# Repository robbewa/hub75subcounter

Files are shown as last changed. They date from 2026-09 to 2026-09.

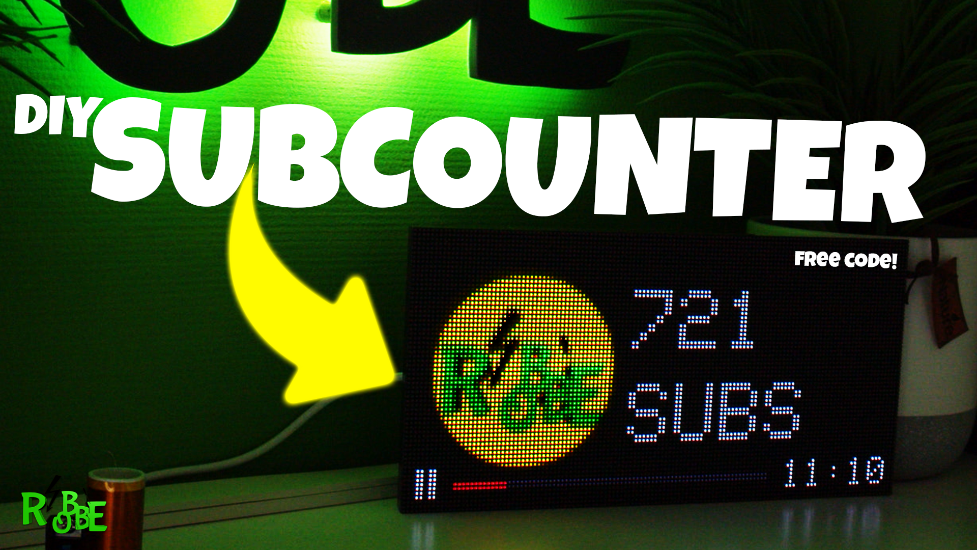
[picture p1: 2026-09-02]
thumb v2.png

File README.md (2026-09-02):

# ESP32 YouTube Subscriber Counter & HUB75 Matrix Display

An open-source, Wi-Fi-connected YouTube subscriber counter and multi-functional clock powered by an ESP32 and a 128x64 HUB75 LED matrix panel. 

It fetches real-time channel statistics via the YouTube Data API, displays a custom channel logo, includes an active YouTube-themed NTP clock, and triggers animated fireworks upon hitting subscriber milestones!

Watch the video (https://www.youtube.com/watch?v=sCw4Do6QDgE)

---

## Features

- **Live YouTube Stats:** Fetches and displays real-time subscriber counts using the YouTube Data API v3.
- **Custom Logo Integration:** Display your own 128x64 channel logo or graphic.
- **NTP Time Sync & YouTube Progress Bar:** Digital clock synced via NTP with a custom progress bar simulating a YouTube video player.
- **Milestone Animations:** Custom animated fireworks show whenever a new subscriber joins or a milestone is reached.
- **Automated Activity Scheduler:** Screen automatically turns on at 09:00 and off at 22:00 to save power and extend LED lifespan.
- **Display Rotation Support:** Software-configurable screen orientation (0°, 90°, 180°, 270°).
- **Custom 3D Printed Stand:** Dedicated magnetic enclosure with integrated USB-C power delivery.

---

## Hardware Requirements

- **Microcontroller:** ESP32 (e.g., ESP32-WROOM-32 / ESP32-S3)
- **Display Panel:** HUB75 LED Matrix Panel (128x64 pixels)
- **Power Supply:** 5V Power Supply / USB-C (ensure sufficient current capacity for the LED matrix)
- **Connector:** HUB75 ribbon cable (soldered directly to ESP32 for signal stability)
- **Enclosure:** Custom 3D-printed magnetic stand (STL files provided below)

---

## Pinout & Wiring Guide

>  **Important:** Standard jumper wires can cause severe signal interference on HUB75 panels. For optimal stability, it is strongly recommended to cut a HUB75 ribbon cable and solder the wires directly to the ESP32 GPIO pins.

| HUB75 Cable Wire | Function | ESP32 GPIO Pin |
| :--- | :--- | :--- |
| Wire 1 | R1 (Red 1) | GPIO 25 |
| Wire 2 | G1 (Green 1) | GPIO 26 |
| Wire 3 | B1 (Blue 1) | GPIO 27 |
| Wire 4 | GND | GND |
| Wire 5 | R2 (Red 2) | GPIO 14 |
| Wire 6 | G2 (Green 2) | GPIO 12 |
| Wire 7 | B2 (Blue 2) | GPIO 13 |
| Wire 8 | GND | GND |
| Wire 9 | A (Row Address) | GPIO 33 |
| Wire 10 | B (Row Address) | GPIO 32 |
| Wire 11 | C (Row Address) | GPIO 22 |
| Wire 12 | D (Row Address) | GPIO 19 |
| Wire 13 | CLK (Clock) | GPIO 4 |
| Wire 14 | LAT / LATCH | GPIO 2 |
| Wire 15 | OE (Output Enable) | GPIO 15 |
| Wire 16 | GND | GND |

*Note: Ensure the ESP32 ground (GND) and the HUB75 5V external power supply ground are connected to a common ground.*

---

## Quick Start & Setup

### 1. Prerequisites
- Install [Arduino IDE](https://www.arduino.cc/en/software).
- Add ESP32 Board Support to your Arduino IDE.
- Required Libraries: Install `ESP32-HUB75-MatrixPanel-I2S-DMA`, `ArduinoJson`, and `NTPClient` via the Library Manager.
- Obtain a YouTube Data API Key via the [Google Cloud Console](https://console.cloud.google.com/).

### 2. Preparing Image Assets
1. Create or resize your image to **128x64 pixels** in an image editor.
2. Convert the image using [image2cpp](https://endroad.net/env/image2cpp/).
3. Export the file as a `.h` header array and place it in your project directory.

### 3. Configuration & Flash
1. Clone or download this repository:
   ```bash
   git clone https://github.com/your-username/esp32-youtube-counter.git
   ```

2. Open the project in Arduino IDE and select your ESP32 board.
3. Update your credentials in the main sketch / configuration file:
```cpp
const char* ssid       = "YOUR_WIFI_SSID";
const char* password   = "YOUR_WIFI_PASSWORD";
const char* apiKey     = "YOUR_YOUTUBE_API_KEY";
const char* channelId  = "YOUR_YOUTUBE_CHANNEL_ID";
```

4. Set your preferred display orientation (`0`, `1`, `2`, or `3`).
5. Hold the **BOOT** button on your ESP32 (if required) and upload the code.

---

## 3D Printed Stand (Enclosure)

The repository includes printable STL files for a custom rear-mounting stand featuring:

* Recessed slots for M3 heat-set inserts / bolts.
* Magnet mounts for quick snap-on backplate removal.
* Integrated cutout for a panel-mount USB-C extension port.

 Find all model files in the `/3D_Files` directory.

---

## Video & Build Guide

Want to see how this project was built step-by-step or see it in action? Check out the full video tutorial on YouTube:

---

## License & Terms of Use

This project is open-source and shared strictly for personal and educational use.

This work is licensed under a **[Creative Commons Attribution-NonCommercial-ShareAlike 4.0 International License (CC BY-NC-SA 4.0)](https://creativecommons.org/licenses/by-nc-sa/4.0/)**.

```
    -  Attribution Required: You must give appropriate credit to Robbe Wauters and link back to this repository or the original YouTube channel.
    -  No Commercial Use: You may NOT sell, commercialize, package, or monetize this code, project files, or physical derivatives in any form.
    -  ShareAlike: If you remix, transform, or build upon the material, you must distribute your contributions under the same license as the original.

```

---

##  Credits & Author

Designed and developed by **Robbe Wauters**.

If you build your own version of this subscriber counter, feel free to share your build or tag me on social media! If this project helped you, consider subscribing to the channel or dropping a star on this repository.

```

```

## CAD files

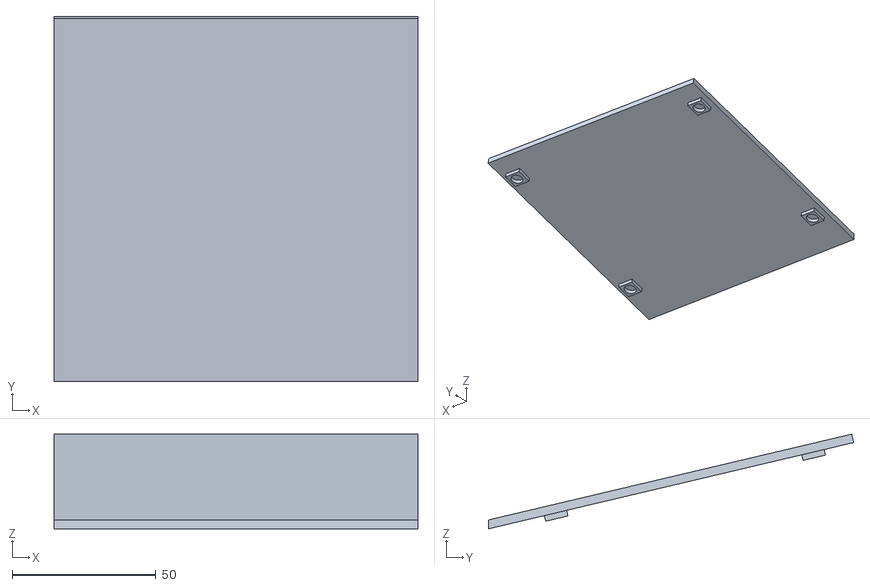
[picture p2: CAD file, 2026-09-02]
3D files/Matrix ledbord boven v1.stl
126.5 x 127.0 x 32.9

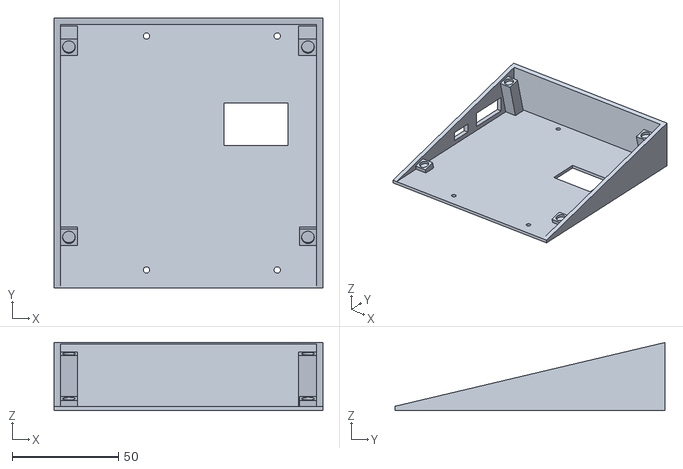
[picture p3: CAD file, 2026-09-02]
3D files/Matrix ledbord onder v1.stl
126.5 x 127.0 x 32.0

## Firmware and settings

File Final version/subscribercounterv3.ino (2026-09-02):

#include <WiFi.h>
#include <HTTPClient.h>
#include <WiFiClientSecure.h>
#include <ArduinoJson.h>
#include <ESP32-HUB75-MatrixPanel-I2S-DMA.h>
#include <time.h>
#include "logorond128x64.h"

const char* ssid     = "jouw wifi netwerk";
const char* password = "jouw wifi wachtwoord";

const char* apiKey    = "jouw api key";
const char* channelId = "jouw channel id";

const char* ntpServer1 = "pool.ntp.org";
const char* ntpServer2 = "time.nist.gov";
const char* timeZone   = "CET-1CEST,M3.5.0,M10.5.0/3";

const int AAN_UUR  = 9;
const int UIT_UUR  = 22;
const uint8_t MAX_HELDERHEID = 15;
const uint8_t FIREWORK_HELDERHEID = 20; 
const unsigned long FETCH_INTERVAL = 600000;
const unsigned long IDLE_DELAY = 50; 

#define PANEL_RES_X 128
#define PANEL_RES_Y 64
#define PANEL_CHAIN 1

const int TEXT_AREA_X = 54;
const int TEXT_AREA_W = PANEL_RES_X - TEXT_AREA_X;

MatrixPanel_I2S_DMA *dma_display = nullptr;
uint32_t vorigAantalSubs = 0;
bool hasSubs = false;
bool schermActief = true;
unsigned long lastFetch = 0;
uint32_t currentSubs = 0;

bool fireworkActive = false;
unsigned long fireworkStartTime = 0;
const unsigned long FIREWORK_DURATION = 30000;
const unsigned long FIREWORK_FRAME_DELAY = 33;
unsigned long lastFrame = 0;
bool fireworkStopping = false;
bool rocketActive = false;
unsigned long nextRocketDelay = 0;

bool testModeActive = false;
int simulatedSubsIncrement = 1;

bool debugNetwork = true;
const unsigned long NETWORK_RETRY_DELAY = 600000;
unsigned long lastNetworkFailure = 0;

struct FireworkParticle {
  float x;
  float y;
  float dx;
  float dy;
  uint16_t color;
  bool alive;
  int prev_x;
  int prev_y;
};

const int MAX_PARTICLES = 250; 
FireworkParticle particles[MAX_PARTICLES];
int particleCount = 0;

int launchX = PANEL_RES_X / 2;
int rocketY = PANEL_RES_Y - 1;
int rocketPrevY = -1;
int normalRocketDestY = 15;
unsigned long phaseStartTime = 0;
int phase = 0; 

const int FINALE_ROCKETS = 5;
struct FinaleRocket {
  int x;
  int y;
  int prevY;
  int destY;
  bool active;
};
FinaleRocket finaleRockets[FINALE_ROCKETS];

uint16_t rgb565(uint8_t r, uint8_t g, uint8_t b) {
  return ((r & 0xF8) << 8) | ((g & 0xFC) << 3) | (b >> 3);
}

void drawClockArea(bool forceRedraw = false) {
  struct tm timeinfo;
  if (!getLocalTime(&timeinfo)) return;

  static int lastSec = -1;
  bool timeChanged = (timeinfo.tm_sec != lastSec);
  
  if (!forceRedraw && !timeChanged) return;
  lastSec = timeinfo.tm_sec;

  const int margin = 3;
  const int textHeight = 7;
  const int baseY = PANEL_RES_Y - margin - textHeight;

  const int textWidth = 29;
  const int timeX = PANEL_RES_X - margin - textWidth;

  if (timeChanged) {
    dma_display->fillRect(timeX, baseY, textWidth, textHeight, 0x0000);
  }

  dma_display->fillRect(margin, baseY, 2, 7, rgb565(255, 255, 255));
  dma_display->fillRect(margin + 3, baseY, 2, 7, rgb565(255, 255, 255));

  char timeText[6];
  snprintf(timeText, sizeof(timeText), "%02d:%02d", timeinfo.tm_hour, timeinfo.tm_min);
  dma_display->setTextSize(1);
  dma_display->setCursor(timeX, baseY);
  dma_display->setTextColor(rgb565(255, 255, 255));
  dma_display->print(timeText);

  const int barStartX = margin + 5 + 4;
  const int barEndX = timeX - 4;
  const int barWidth = barEndX - barStartX; 
  const int barY = baseY + 3;
  
  int elapsedSeconds = timeinfo.tm_min * 60 + timeinfo.tm_sec;
  int fillWidth = map(elapsedSeconds, 0, 3600, 0, barWidth);
  fillWidth = constrain(fillWidth, 0, barWidth);

  dma_display->fillRect(barStartX, barY, barWidth, 2, rgb565(32, 32, 48));
  if (fillWidth > 0) {
    dma_display->fillRect(barStartX, barY, fillWidth, 2, rgb565(230, 33, 23));
  }

  dma_display->setTextSize(2); 
}

void restoreBackgroundPixel(int x, int y) {
  if (x < 0 || x >= PANEL_RES_X || y < 0 || y >= PANEL_RES_Y) return;

  if (x < TEXT_AREA_X) {
    int logo_x = x + 3;
    int logo_y = y;
    
    if (logo_x >= 0 && logo_x < 128 && logo_y >= 0 && logo_y < 64) {
      uint16_t color = logorond128x64[logo_y * 128 + logo_x];
      dma_display->drawPixel(x, y, color);
    } else {
      dma_display->drawPixel(x, y, 0x0000);
    }
  } else {
    dma_display->drawPixel(x, y, 0x0000);
  }
}

void startRocket() {
  launchX = random(10, PANEL_RES_X - 10); 
  rocketY = PANEL_RES_Y - 1;
  rocketPrevY = -1;
  normalRocketDestY = random(5, 25); 
  rocketActive = true;
  phase = 1;
  phaseStartTime = millis();
}

void addExplosion(int centerX, int centerY, int count) {
  for (int i = 0; i < count; i++) {
    if (particleCount >= MAX_PARTICLES) break;
    
    float angle = random(0, 360) * 0.0174533;
    float speed = random(40, 90) / 40.0;
    uint16_t color = rgb565(random(200, 255), random(80, 255), random(0, 255));

    particles[particleCount++] = {
      (float)centerX,
      (float)centerY,
      (float)(cos(angle) * speed * 1.5), 
      (float)(sin(angle) * speed),
      color,
      true,
      centerX,
      centerY
    };
  }
}

void startExplosion(int centerX, int centerY, int count) {
  phaseStartTime = millis();
  particleCount = 0; 
  addExplosion(centerX, centerY, count);
  phase = 2;
}

void startGrandFinale() {
  phaseStartTime = millis();
  particleCount = 0; 
  
  int sectorWidth = PANEL_RES_X / FINALE_ROCKETS; 
  
  for (int i = 0; i < FINALE_ROCKETS; i++) {
    finaleRockets[i].x = random(i * sectorWidth + 4, (i + 1) * sectorWidth - 4);
    finaleRockets[i].y = PANEL_RES_Y - 1;
    finaleRockets[i].prevY = -1;
    finaleRockets[i].destY = random(5, 22); 
    finaleRockets[i].active = true;
  }
  
  phase = 4; 
}

void drawRocketTrail(int x, int y) {
  for (int i = 0; i < 4; i++) {
    int ty = y + i;
    if (ty < PANEL_RES_Y) {
      uint16_t color = rgb565(255, 180 - i * 40, 60);
      dma_display->drawPixel(x, ty, color);
    }
  }
}

void updateExplosion() {
  for (int i = 0; i < particleCount; i++) {
    if (particles[i].alive || particles[i].prev_x != -1) {
      if (particles[i].prev_x >= 0) {
        restoreBackgroundPixel(particles[i].prev_x, particles[i].prev_y);
      }
    }
  }

  bool anyAlive = false;
  for (int i = 0; i < particleCount; i++) {
    if (!particles[i].alive) {
      particles[i].prev_x = -1;
      continue;
    }

    particles[i].x += particles[i].dx;
    particles[i].y += particles[i].dy;
    particles[i].dx *= 0.95; 
    particles[i].dy += 0.12; 

    int nx = round(particles[i].x);
    int ny = round(particles[i].y);

    if (nx < 0 || nx >= PANEL_RES_X || ny < 0 || ny >= PANEL_RES_Y) {
      particles[i].alive = false;
      particles[i].prev_x = -1; 
    } else {
      particles[i].prev_x = nx;
      particles[i].prev_y = ny;
      
      if (random(0, 100) < 10) {
        particles[i].color = rgb565(random(180, 255), random(80, 255), random(0, 255));
      }
      anyAlive = true;
    }
  }
}

bool anyExplosionAlive() {
  for (int i = 0; i < particleCount; i++) {
    if (particles[i].alive) return true;
  }
  return false;
}

void drawExplosion() {
  for (int i = 0; i < particleCount; i++) {
    if (particles[i].alive) {
      dma_display->drawPixel(particles[i].prev_x, particles[i].prev_y, particles[i].color);
    }
  }
}

void drawTextOnly(uint32_t subs, bool valid) {
  char text[16];
  if (!valid) {
    strcpy(text, "--");
  } else {
    snprintf(text, sizeof(text), "%u", subs);
  }
  dma_display->setCursor(54, 13);
  dma_display->print(text);
  dma_display->setCursor(54, 35);
  dma_display->print("SUBS");
}

void drawTextArea(uint32_t subs, bool valid) {
  char text[16];
  if (!valid) {
    strcpy(text, "--");
  } else {
    snprintf(text, sizeof(text), "%u", subs);
  }
  
  dma_display->fillRect(TEXT_AREA_X, 0, TEXT_AREA_W, 53, 0x0000);
  dma_display->setCursor(54, 13);
  dma_display->print(text);
  dma_display->setCursor(54, 35);
  dma_display->print("SUBS");
}

void restoreFullCleanScreen(uint32_t subs, bool valid) {
  dma_display->fillScreen(0x0000);
  dma_display->drawRGBBitmap(-3, 0, logorond128x64, PANEL_RES_X, PANEL_RES_Y);
  drawTextArea(subs, valid);
  drawClockArea(true);
}

void startFirework() {
  if (fireworkActive) return;

  fireworkActive = true;
  fireworkStopping = false;
  fireworkStartTime = millis();
  lastFrame = 0;
  phase = 0;
  dma_display->setBrightness8(FIREWORK_HELDERHEID);
  
  drawTextArea(currentSubs, hasSubs); 
  startRocket();
  lastFetch = millis();
}

void renderFireworkFrame(uint32_t subs, bool valid) {
  unsigned long now = millis();
  if (now - lastFrame < FIREWORK_FRAME_DELAY) return;
  lastFrame = now;

  if (phase == 1) {
    if (rocketPrevY != -1) {
      for (int i = 0; i < 4; i++) {
        int ty = rocketPrevY + i;
        if (ty < PANEL_RES_Y) restoreBackgroundPixel(launchX, ty);
      }
    }

    rocketPrevY = rocketY;
    rocketY -= 2;

    if (rocketY >= normalRocketDestY) {
      drawRocketTrail(launchX, rocketY);
      dma_display->drawPixel(launchX, rocketY, rgb565(255, 255, 0));
    } else {
      rocketActive = false;
      for (int i = 0; i < 4; i++) {
        int ty = rocketPrevY + i;
        if (ty < PANEL_RES_Y) restoreBackgroundPixel(launchX, ty);
      }
      startExplosion(launchX, rocketY, 48); 
    }
  } 
  else if (phase == 2) {
    updateExplosion(); 
    drawExplosion();   
    
    if (!anyExplosionAlive()) {
      phase = 3;
      phaseStartTime = millis();
      nextRocketDelay = random(50, 250); 
    }
  } 
  else if (phase == 3) { 
    if (now - fireworkStartTime >= FIREWORK_DURATION && !fireworkStopping) {
      fireworkStopping = true;
      startGrandFinale(); 
      return;
    }

    unsigned long elapsed = now - phaseStartTime;
    if (elapsed >= nextRocketDelay) {
      startRocket();
    }
  }
  else if (phase == 4) { 
    bool anyRocketMoving = false;

    for (int i = 0; i < FINALE_ROCKETS; i++) {
      if (!finaleRockets[i].active) continue;

      if (finaleRockets[i].prevY != -1) {
        for (int t = 0; t < 4; t++) {
          int ty = finaleRockets[i].prevY + t;
          if (ty < PANEL_RES_Y) restoreBackgroundPixel(finaleRockets[i].x, ty);
        }
      }

      finaleRockets[i].prevY = finaleRockets[i].y;
      finaleRockets[i].y -= 2; 

      if (finaleRockets[i].y >= finaleRockets[i].destY) {
        drawRocketTrail(finaleRockets[i].x, finaleRockets[i].y);
        dma_display->drawPixel(finaleRockets[i].x, finaleRockets[i].y, rgb565(255, 255, 0));
        anyRocketMoving = true;
      } else {
        finaleRockets[i].active = false;
        for (int t = 0; t < 4; t++) {
          int ty = finaleRockets[i].prevY + t;
          if (ty < PANEL_RES_Y) restoreBackgroundPixel(finaleRockets[i].x, ty);
        }
        addExplosion(finaleRockets[i].x, finaleRockets[i].destY, 48);
      }
    }

    updateExplosion(); 
    drawExplosion();

    if (!anyRocketMoving) {
      phase = 5; 
    }
  }
  else if (phase == 5) { 
    updateExplosion();
    drawExplosion();

    if (!anyExplosionAlive()) {
      fireworkActive = false;
      phase = 0;
      dma_display->setBrightness8(MAX_HELDERHEID);

      if (testModeActive) {
        testModeActive = false;
        currentSubs = vorigAantalSubs; 
      } else {
        if (valid) vorigAantalSubs = currentSubs;
      }

      drawTextArea(currentSubs, valid); 
    }
  }

  if (phase >= 1 && phase <= 5) {
    drawTextOnly(subs, valid);
    drawClockArea(true);
  }
}

void startTestSubscriber() {
  if (!hasSubs) return;
  testModeActive = true;
  Serial.println("[TEST] Test-subscriber geactiveerd voor 30s");
  
  currentSubs = vorigAantalSubs + simulatedSubsIncrement;
  if (!fireworkActive) startFirework();
}

void stopTestSubscriber() {
  if (!testModeActive) return;
  
  testModeActive = false;
  fireworkActive = false; 
  Serial.println("[TEST] Test-subscriber gedeactiveerd. Echte teller wordt direct teruggezet...");
  
  currentSubs = vorigAantalSubs; 
  dma_display->setBrightness8(MAX_HELDERHEID);
  drawTextArea(currentSubs, hasSubs);
}

void checkSerialCommands() {
  if (!Serial || !Serial.available()) return;
  String cmd = Serial.readStringUntil('\n');
  cmd.trim();
  
  if (cmd.equalsIgnoreCase("test")) {
    startTestSubscriber();
    return;
  }
  
  if (cmd.equalsIgnoreCase("test off") || cmd.equalsIgnoreCase("stop test")) {
    stopTestSubscriber();
    return;
  }

  if (cmd.equalsIgnoreCase("debug on") || cmd.equalsIgnoreCase("debug on\r")) {
    debugNetwork = true;
    Serial.println("[DEBUG] Network debug ON");
    return;
  }
  if (cmd.equalsIgnoreCase("debug off") || cmd.equalsIgnoreCase("debug off\r")) {
    debugNetwork = false;
    Serial.println("[DEBUG] Network debug OFF");
    return;
  }
}

void setTimeFromNTP() {
  configTzTime(timeZone, ntpServer1, ntpServer2);
  Serial.print("Wachten op NTP tijd-synchronisatie");

  struct tm timeinfo;
  int counter = 0;
  while (!getLocalTime(&timeinfo) && counter < 30) {
    delay(100);
    yield();
    Serial.print(".");
    counter++;
  }
  Serial.println("\nTijd gesynchroniseerd!");
}

bool isDisplayTime() {
  struct tm timeinfo;
  if (!getLocalTime(&timeinfo)) {
    Serial.println("[WARN] Kon lokale tijd niet ophalen. Scherm blijft aan.");
    return true;
  }
  int huidigUur = timeinfo.tm_hour;
  return (huidigUur >= AAN_UUR && huidigUur < UIT_UUR);
}

bool connectWiFi() {
  if (WiFi.status() == WL_CONNECTED) {
    return true;
  }
  WiFi.mode(WIFI_STA);
  WiFi.begin(ssid, password);

  unsigned long start = millis();
  while (WiFi.status() != WL_CONNECTED) {
    if (millis() - start > 10000) {
      Serial.println("[WARN] WiFi connect timeout");
      return false;
    }
    delay(100);
    yield();
  }
  Serial.println("\nWiFi verbonden!");
  Serial.print("IP Adres: ");
  Serial.println(WiFi.localIP());
  return true;
}

bool getSubscriberCount(uint32_t &subs) {
  if (!connectWiFi()) {
    Serial.println("[ERROR] Geen WiFi verbinding!");
    return false;
  }

  if (millis() - lastNetworkFailure < NETWORK_RETRY_DELAY && lastNetworkFailure != 0 && hasSubs) {
    Serial.println("[WARN] Google HTTPS is recentelijk geblokkeerd; toon laatst bekende waarde.");
    subs = vorigAantalSubs;
    return false;
  }

  WiFiClientSecure client;
  client.setInsecure(); 
  client.setTimeout(15000);

  HTTPClient http;
  http.setTimeout(15000);
  
  String requestURL = String("https://www.googleapis.com/youtube/v3/channels?part=statistics&id=") + channelId + "&key=" + apiKey;
  requestURL.reserve(220); 
  
  if (!http.begin(client, requestURL)) {
    Serial.println("[ERROR] Kon HTTP verbinding niet initialiseren.");
    if (hasSubs) subs = vorigAantalSubs;
    return false;
  }

  int httpCode = http.GET();
  if (debugNetwork) {
    Serial.print("[HTTP] Response code: ");
    Serial.println(httpCode);
  }

  if (httpCode <= 0 || httpCode != HTTP_CODE_OK) {
    lastNetworkFailure = millis();
    Serial.print("[HTTP] GET failed: ");
    if (httpCode <= 0) {
      Serial.println(http.errorToString(httpCode)); 
    } else {
      Serial.println("Server error code: " + String(httpCode)); 
    }
    http.end();
    if (hasSubs) {
      subs = vorigAantalSubs;
    }
    return false;
  }

  String payload = http.getString();
  http.end();

  StaticJsonDocument<512> doc;
  DeserializationError error = deserializeJson(doc, payload);
  if (error || !doc["items"].is<JsonArray>() || doc["items"].size() == 0) {
    Serial.println("[ERROR] JSON parsing mislukt of kanaal niet gevonden.");
    if (hasSubs) {
      subs = vorigAantalSubs;
    }
    return false;
  }

  subs = doc["items"][0]["statistics"]["subscriberCount"].as<uint32_t>();

  lastNetworkFailure = 0;
  Serial.print("[SUCCESS] Subs ververst: ");
  Serial.println(subs);
  return true;
}

void setup() {
  delay(2000);
  Serial.begin(115200);

  HUB75_I2S_CFG::i2s_pins custom_pins = {
    26, 27, 25,
    12, 13, 14,
    33, 32, 22,
    19, 23,
    2, 15, 4
  };

  HUB75_I2S_CFG mxconfig(PANEL_RES_X, PANEL_RES_Y, PANEL_CHAIN, custom_pins, HUB75_I2S_CFG::SHIFTREG);
  mxconfig.i2sspeed = HUB75_I2S_CFG::HZ_10M;
  mxconfig.double_buff = false; 
  mxconfig.clkphase = false;
  mxconfig.latch_blanking = 4;

  dma_display = new MatrixPanel_I2S_DMA(mxconfig);
  dma_display->begin();
  dma_display->setRotation(2);
  dma_display->setBrightness8(MAX_HELDERHEID);
  dma_display->clearScreen();
  dma_display->setTextWrap(false);
  dma_display->setTextSize(2);
  dma_display->setTextColor(dma_display->color565(255, 255, 255));

  randomSeed(analogRead(0));

  if (!connectWiFi()) {
    Serial.println("[WARN] WiFi niet verbonden; setup gaat verder met de laatst bekende waarden.");
  }

  setTimeFromNTP();
  if (getSubscriberCount(currentSubs)) {
    vorigAantalSubs = currentSubs;
    hasSubs = true;
  }
  
  restoreFullCleanScreen(currentSubs, hasSubs);
  lastFetch = millis();
}

void loop() {
  bool moetAanStaan = isDisplayTime();

  if (moetAanStaan) {
    checkSerialCommands();
    
    if (!schermActief) {
      Serial.println("[TIMER] Scherm gaat AAN (10:00 - 22:00)");
      dma_display->setBrightness8(MAX_HELDERHEID);
      if (!connectWiFi()) {
        Serial.println("[WARN] WiFi reconnect mislukt; scherm blijft actief met laatst bekende data.");
      }
      schermActief = true;
      hasSubs = false;
      currentSubs = 0;
      vorigAantalSubs = 0;
      restoreFullCleanScreen(currentSubs, hasSubs); 
    }

    if (!fireworkActive && !testModeActive && (millis() - lastFetch > FETCH_INTERVAL || !hasSubs)) {
      uint32_t nieuweSubs = vorigAantalSubs;
      if (getSubscriberCount(nieuweSubs)) {
        if (hasSubs && nieuweSubs > vorigAantalSubs) {
          currentSubs = nieuweSubs;
          startFirework();
        }
        if (!fireworkActive) {
          currentSubs = nieuweSubs;
        }
        vorigAantalSubs = nieuweSubs;
        hasSubs = true;
      } else if (hasSubs) {
        currentSubs = vorigAantalSubs;
        hasSubs = true;
      }
      lastFetch = millis();
    }

    if (hasSubs && currentSubs != vorigAantalSubs && !fireworkActive) {
      drawTextArea(currentSubs, true); 
      vorigAantalSubs = currentSubs;
    }

    if (fireworkActive) {
      renderFireworkFrame(currentSubs, hasSubs);
      delay(1);
      return;
    }

    drawClockArea();

  } else {
    if (schermActief) {
      Serial.println("[TIMER] Scherm gaat UIT (Nachtstand)");
      dma_display->clearScreen();
      dma_display->setBrightness8(0);
      WiFi.disconnect(true, false);
      WiFi.mode(WIFI_OFF);
      schermActief = false;
      fireworkActive = false;
      testModeActive = false;
      hasSubs = false;
      vorigAantalSubs = 0;
    }
  }

  delay(IDLE_DELAY); 
}

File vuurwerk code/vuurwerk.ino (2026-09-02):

#include <ESP32-HUB75-MatrixPanel-I2S-DMA.h>

#define PANEL_RES_X 128
#define PANEL_RES_Y 64
#define PANEL_CHAIN 1

MatrixPanel_I2S_DMA *dma_display = nullptr;

struct FireworkParticle {
  float x;
  float y;
  float dx;
  float dy;
  uint16_t color;
  bool alive;
};

FireworkParticle particles[64];
int particleCount = 0;
int launchX = PANEL_RES_X / 2;
int rocketY = PANEL_RES_Y - 1;
bool rocketActive = false;
unsigned long lastFrame = 0;
unsigned long phaseStartTime = 0;
int phase = 0;
uint16_t bgColor;

uint16_t rgb565(uint8_t r, uint8_t g, uint8_t b) {
  return ((r & 0xF8) << 8) | ((g & 0xFC) << 3) | (b >> 3);
}

void startRocket() {
  launchX = random(20, PANEL_RES_X - 20);
  rocketY = PANEL_RES_Y - 1;
  rocketActive = true;
  phase = 1;
  phaseStartTime = millis();
}

void startExplosion() {
  phaseStartTime = millis();
  particleCount = 0;
  for (int i = 0; i < 48; i++) {
    float angle = random(0, 360) * 0.0174533;
    float speed = random(40, 90) / 40.0;
    particles[particleCount++] = {
      (float)launchX,
      (float)rocketY,
      cos(angle) * speed,
      sin(angle) * speed,
      rgb565(random(200, 255), random(80, 255), random(0, 255)),
      true
    };
  }
  phase = 2;
}

void drawRocketTrail(int x, int y) {
  for (int i = 0; i < 4; i++) {
    int ty = y + i;
    if (ty < PANEL_RES_Y) {
      uint16_t color = rgb565(255, 180 - i * 40, 60);
      dma_display->drawPixel(x, ty, color);
    }
  }
}

void updateExplosion() {
  bool anyAlive = false;
  for (int i = 0; i < particleCount; i++) {
    if (!particles[i].alive) continue;
    particles[i].x += particles[i].dx;
    particles[i].y += particles[i].dy;
    particles[i].dx *= 0.95;
    particles[i].dy += 0.12;
    if (particles[i].x < 0 || particles[i].x >= PANEL_RES_X || particles[i].y < 0 || particles[i].y >= PANEL_RES_Y) {
      particles[i].alive = false;
      continue;
    }
    if (random(0, 100) < 10) {
      particles[i].color = rgb565(random(180, 255), random(80, 255), random(0, 255));
    }
    anyAlive = true;
  }
  if (!anyAlive) phase = 3;
}

void drawExplosion() {
  for (int i = 0; i < particleCount; i++) {
    if (!particles[i].alive) continue;
    int px = round(particles[i].x);
    int py = round(particles[i].y);
    dma_display->drawPixel(px, py, particles[i].color);
  }
}

void setup() {
  delay(1000);

  HUB75_I2S_CFG::i2s_pins custom_pins = {
    26, 27, 25,
    12, 13, 14,
    33, 32, 22,
    19, 23,    
    2,  15, 4  
  };

  HUB75_I2S_CFG mxconfig(
    PANEL_RES_X, PANEL_RES_Y, PANEL_CHAIN,
    custom_pins, HUB75_I2S_CFG::SHIFTREG
  );

  dma_display = new MatrixPanel_I2S_DMA(mxconfig);
  dma_display->begin();
  dma_display->setBrightness8(80);
  dma_display->clearScreen();

  randomSeed(analogRead(0));
  bgColor = rgb565(0, 0, 16);
  startRocket();
}

void loop() {
  unsigned long now = millis();
  if (now - lastFrame < 40) return;
  lastFrame = now;

  dma_display->fillScreen(0x0000);

  if (phase == 1) {
    drawRocketTrail(launchX, rocketY);
    dma_display->drawPixel(launchX, rocketY, rgb565(255, 255, 255));
    rocketY -= 2;
    if (rocketY < 18) {
      rocketActive = false;
      startExplosion();
    }
  } else if (phase == 2) {
    updateExplosion();
    drawExplosion();
  } else if (phase == 3) {
    unsigned long elapsed = now - phaseStartTime;
    if (elapsed >= 80) {
      startRocket();
    }
  }

  delay(20);
}

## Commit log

2026-08-31 Enhance README with project details and instructions
    Added detailed project description, features, hardware requirements, wiring guide, quick start instructions, and licensing information for the ESP32 YouTube Subscriber Counter.
2026-09-02 ESP32 + image/logo
2026-09-02 Rename Matrix ledbord boven v1.stl to 3D files/Matrix ledbord boven v1.stl
    [Matrix ledbord boven v1.stl]
2026-09-02 Rename Matrix ledbord onder v1.stl to 3D files/Matrix ledbord onder v1.stl
    [Matrix ledbord onder v1.stl]
